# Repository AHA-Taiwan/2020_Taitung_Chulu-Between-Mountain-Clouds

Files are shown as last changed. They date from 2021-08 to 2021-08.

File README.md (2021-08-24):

# 2020｜台東初鹿｜山嵐。之間
## _Chulu Between the Mountain Clouds_, Taitung, Taiwan

>Humanitarian Architecture in Taitung<br/>
>
>以台灣國產木材為主體構築材料之人道建築案例，主要材料來源自：行政院農業委員會林務局「台灣木材」標章、正昌製材有限公司「台灣杉」及東皇昌五金工具有限公司。由 L.A. Lab 俐場域建築設計發展設計，與公東高工家具木工科/室內設計科/建築科、南港高工土木科、淡江大學建築研究所和雲林科技大學室內設計與建築系等學校單位合作進行實作。以山行為意象，行為活動為風，使人行自然共構穿梭其中。篩入的樹影搖曳數算著時光，試圖以空間為時間的記錄器，路徑則為不同時序打造的環境圖像，提供初鹿中學多一個停留與遊歷場所的可能。<br/>

## 基地環境：<br/>
台灣東南地區，北回歸線以南，有焚風、颱風、東北季風，海風具高度鹽分，設計時需注意材料防潮防蝕保護。<br/>
* 基地環境氣象資料：https://www.cwb.gov.tw/V8/C/W/County/County.html?CID=10014 <br/>
* 氣象觀測歷史紀錄：<br/>
  https://e-service.cwb.gov.tw/HistoryDataQuery/DayDataController.do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 <br/>
  
* 台東縣氣候月平均氣溫、月平均降雨量、風速與相對濕度數據圖表<br/>
 （取自交通部中央氣象局，統計期間為 1991-2020年）<br/>



* Google Map 位置：https://goo.gl/maps/nYVf215Q8UMeJW5S6  <br/>


***
## 專案介紹：<br/>

* 主要建材：台灣杉 [ 3.8 x 8.9 x 360 cm ] 尺寸。
  <br/>
* 數位模型［ 整體木構 3D ］：https://skfb.ly/op8NG

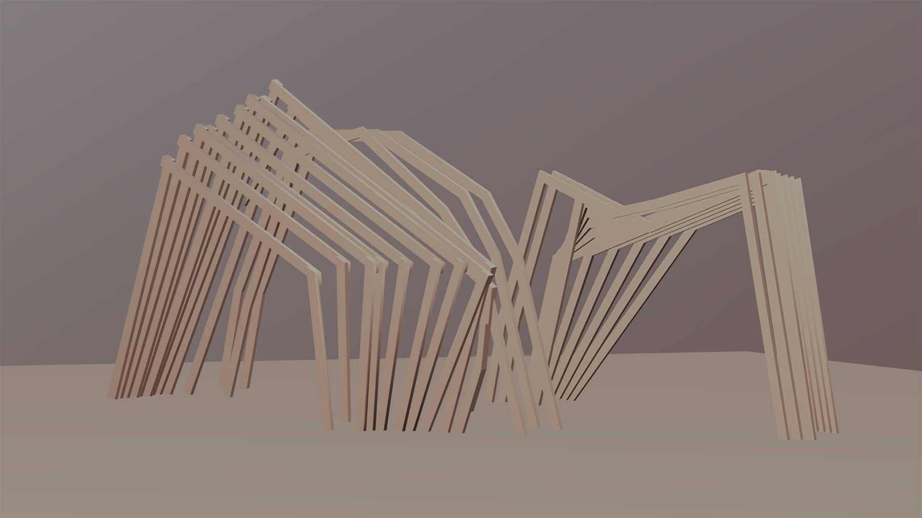
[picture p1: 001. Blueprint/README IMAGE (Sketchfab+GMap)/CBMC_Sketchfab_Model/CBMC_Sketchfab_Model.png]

<br/>
<br/>
***
## 如何達成合作建造：<br/>
* 請參閱［初次合作建造就上手 Collab-Const-Quick-Guide］：<br/>
https://github.com/AHA-Taiwan/Collab-Const-Quick-Guide/wiki <br/>
***
## 確保工作安全：<br/>
* 請參閱［合作建造-安全規範 Collab-Const-Safety］：<br/>
https://github.com/AHA-Taiwan/Collab-Const-Safety/wiki <br/>
***
## 探索合作資源：<br/>
* 請參閱［合作建造-資源探索 Collab-Const-Source］：<br/>
https://github.com/AHA-Taiwan/Collab-Const-Source/wiki <br/>
***
## 取得建造知識：<br/>
* 關於一般的常用構造技術（Techniques），請參閱［合作建造-學習知識 Collab-Const-Learning］：<br/>
https://github.com/AHA-Taiwan/Collab-Const-Learning/wiki <br/>
* 關於本案的特殊構築技術（Tectonic）， 請參閱［本案資料夾 002. Handbook］：<br/>
https://github.com/AHA-Taiwan/2020_Taitung_Chulu-Between-the-Mountain-Clouds/tree/main/002.%20Handbook<br/>
***

> #### 歡迎參與專案開發，Branch合併可向專案管理者提出請求

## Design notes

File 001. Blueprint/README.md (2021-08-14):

2D CAD (.dwg)<br/>
2D PDF<br/>
3D Models (.skp)<br/>
README IMAGE (Sketchfab+GMap)<br/>

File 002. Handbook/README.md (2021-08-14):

Assembly-Object Coding--物件組裝編碼<br/>
Constr-Process Handbook (pdf+ppt)--施工手冊與簡報<br/>
Constr-Process Sheet (.doc)--工項工序表<br/>

Constr-Method --施工工法, Link: https://drive.google.com/drive/u/4/folders/1Tx6Cp3CPNwddxzzepcwecKHZT5yJOXi1

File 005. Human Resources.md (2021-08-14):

# 專業者佈局與人力成本紀錄 
主要紀錄整體施工過程中，專業者、準專業者、非專業者於不同工項所花費時數，從中可間接推估建造施工人力經費及時間成本。
專業者M、準專業者P、非專業者N，當地人加註C

***
## 一、基礎施工
|人力編碼|當地人|工作總時數(hrs)|請工|換工|志工|
|:-:|:-:|:-:|:-:|:-:|:-:|
|M01 | |8 | | |V |
|M02 | |8 | | |V |
|M03 | |8  | | |V |
|P01 | |8 | | |V |
|P02 | |8 | | |V |
|P04 | |8 | | |V |
|P05 | |8 | | |V |
|P06 | |8 | | |V |
|P07 | |8 | | |V |
|P08 | |8 | | |V |
|P09 | |8 | | |V |
|P010 | |8 | | |V |
|P011 | |8 | | |V |
|P012 | |8 | | |V |
***
## 二、桿件結構
|人力編碼|當地人|工作總時數(hrs)|請工|換工|志工|
|:-:|:-:|:-:|:-:|:-:|:-:|
|M01 | |48 | | |V |
|M02 | |48 | | |V |
|M03 | |48 | | |V |
|P01 | |48 | | |V |
|P02 | |48 | | |V |
|P04 | |48 | | |V |
|P05 | |48 | | |V |
|P06 | |48 | | |V |
|P07 | |48 | | |V |
|P08 | |48 | | |V |
|P09 | |48 | | |V |
|P010 | |48 | | |V |
|P011 | |48 | | |V |
|P012 | |48 | | |V |
***
## 三、表面處理（上護木漆）
|人力編碼|當地人|工作總時數(hrs)|請工|換工|志工|
|:-:|:-:|:-:|:-:|:-:|:-:|
|M01 | |16 | | |V |
|M02 | |16 | | |V |
|M03 | |16 | | |V |
|P01 | |16 | | |V |
|P02 | |16 | | |V |
|P04 | |16 | | |V |
|P05 | |16 | | |V |
|P06 | |16 | | |V |
|P07 | |16 | | |V |
|P08 | |16 | | |V |
|P09 | |16 | | |V |
|P010 | |16 | | |V |
|P011 | |16 | | |V |
|P012 | |16 | | |V |
***

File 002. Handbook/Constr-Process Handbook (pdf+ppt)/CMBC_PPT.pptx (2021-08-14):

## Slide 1

2020

初鹿義築．工作手冊

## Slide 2

目錄

一．活動簡述．．．．．．．．．．．．１
二．自備物品與重要叮嚀．．．．．．．２
三．每日作息與行事曆．．．．．．．．４
四．交通與地圖．．．．．．．．．．．６
五．附件．．．．．．．．．．．．．．７
各組分工負責人
值日生班表
通訊錄

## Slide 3

１

一．活動簡述

時間：2020年8月19日 —2020年8月28日
地點：台東縣卑南鄉初鹿國中（台東縣卑南鄉明峰村忠孝路2號）
住宿：初鹿國中圖書室

夏天是明亮的，太陽是辣的，
青春的心是熱血的。
離開了繁華，重返樸實；
捨棄了依賴，回歸自立。

參與團體

外界交流

聯新文教基金會
台東初鹿教會
台東捷陞租車

材料贊助

行政院農委會林務局
正昌製材（台灣杉）
東皇昌五金行

俐場域建築設計
納樊司工作室
公東高工
家具木工科／室內設計科／建築科
義築工具圖書館
老麥農場露營區
台東縣政府文化處
社團法人台東縣巴蘭文化發展協會
社團法人台灣義築協會

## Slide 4

２

二．自備物品與重要叮嚀

換洗衣物 | 輕便工作服／衣架／曬衣夾／塑膠袋／洗衣用具／肥皂
盥洗用品 | 潔牙用品／毛巾／沐浴用品／吹風機
個人衛生品 | 衛生紙／濕紙巾／生理用品
個人藥物 | 健保卡／防蚊液／防曬乳／藥膏／個人用藥
必備物品 | 手電筒／睡袋／麥克筆／抹布
餐具 | 環保餐具／水壺
其他 | 帽子／外套／雨具／筆記／糧食／相機／袖套 足夠的零用金＆快樂心

重要叮嚀

1. 校園蛇類出沒，夜間活動務必攜帶手電筒，並尊重當地生態環境 。
2. 為避免影響施工進度，請按作息表活動，請勿飲酒 。
3. 避免使用香味濃郁的盥洗用品，易引來蚊蟲 。
4. 請留意貴重物品 。
5. 請注意當地禁忌，活動請結伴同行 。
6. 當地提款與融資服務不便，請攜帶足夠的現金 。
7. 施工區域內請勿穿脫鞋或涼鞋，並時時補充水分。
8. 由於浴室數量有限，洗澡時間限制十分鐘。

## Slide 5

３

最重要的三件事！！
1. 晚間收工前30分鐘，清點材料、工具
2. 收工前15分鐘，整理工作環境
3. 工地危險，務必攜帶安全帽，著長褲及全包覆鞋，勿著涼拖鞋
-工具配件務必妥善放回它的位置，切勿亂放
-建材勿隨意放置，會影響材料品質與建築壽命
-廢料勿扔棄，做好資源管理，這是對建築過程的尊重
-離隊務必告知組員、組長，個人行為將影響全體
-注意言行、態度，對自己負責，也尊重合作夥伴
-我們是一個大團體，務必保持與其他單位的良好互動
-我們是一個共同體，請關心身邊的伙伴，發揮自己的價值

施工注意事項

做一個謙卑的實踐者，感恩這份學習的機會

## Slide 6

４

三．每日作息與行事曆

（時間可能依每日天候狀況有所調整）

時間 | 活動 | 備註
0630 | Good Morning | 宿舍長叫醒大家
0630–0700 | 盥洗準備
0700–0730 | 活力早餐 | 生活組提前準備
0730–1200 | 木構GO GO！ | 施工組開工
1200–1300 | 午餐充電 | 生活組準備
1300–1730 | 木構GO GO GO！ | 施工組開工
1730–1830 | 晚餐時光 | 生活組準備
1830–1900 | 工作會議 | 進度／工地狀況檢討
1900–2000 | 洗澎澎 | 超時斷水電！
2000–2200 | 小組／個人時間 | 工作日誌／影音整理
2200 | 睡飽睡好 | 十點準時熄燈

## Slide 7

５

行事曆

08/19 （三）

認識大家／基礎前置加工

08/21 （五）

08/20 （四）

基礎前置加工／放樣／灌漿

木料分類標號／尺寸標記

08/23 （日）

08/22 （六）

木料加工：斬斷／引孔／導角

木料加工：斬斷／引孔／導角

08/24 （一）

木構系統單元化組裝

08/25 （二）

08/26 （三）

木構系統單元化組裝

木構單元與基礎固定

08/27 （四）

08/28 （五）

表面處理／護木漆／環境清潔

表面處理／護木漆／環境清潔／撤收

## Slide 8

６

四．交通與地圖

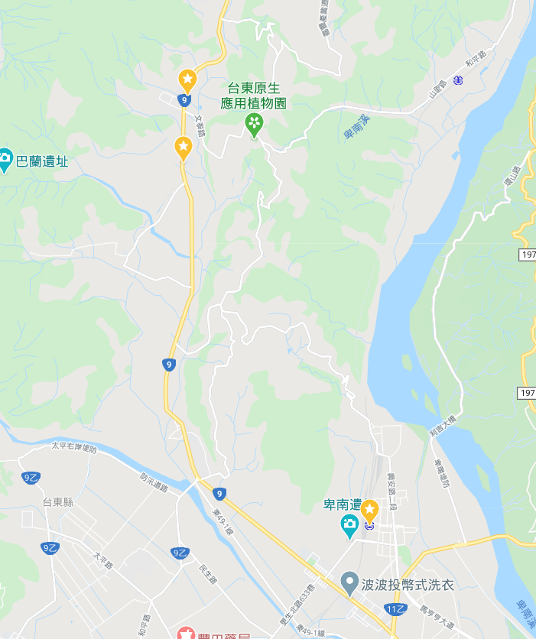
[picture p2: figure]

初鹿教會

盥洗

初鹿國中

加工／施工／住宿

台東車站

由　臺東車站　前往　初鹿國中

步行（15分鐘）至南王站牌
搭乘8171號公車（45分鐘）至初鹿國中

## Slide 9

８

值日生班表

日期 | 生活值日生 | 住宿值日生
8/19 | 瑋聖 仁楷 | 正威 昊翰
8/20 | 偵慧 文慧 | 玥綾 柏翔
8/21 | 仁楷 正威 | 昊翰 震洋
8/22 | 文慧 玥綾 | 柏翔 甫亘
8/23 | 正威 昊翰 | 震洋 瑋聖
8/24 | 玥綾 柏翔 | 甫亘 偵慧
8/25 | 昊翰 震洋 | 瑋聖 仁楷
8/26 | 柏翔 甫亘 | 偵慧 文慧
8/27 | 震洋 瑋聖 | 仁楷 正威
8/28 | 甫亘 偵慧 | 文慧 玥綾

住宿值日生工作
1. 寢室環境清潔
2. 廁所清潔及垃圾清理
3. 浴廁清潔

生活值日生工作
1. 工作環境整理
2. 餐後、廚餘整理
3. 清洗、收拾餐具
4. 搬運、發放食物

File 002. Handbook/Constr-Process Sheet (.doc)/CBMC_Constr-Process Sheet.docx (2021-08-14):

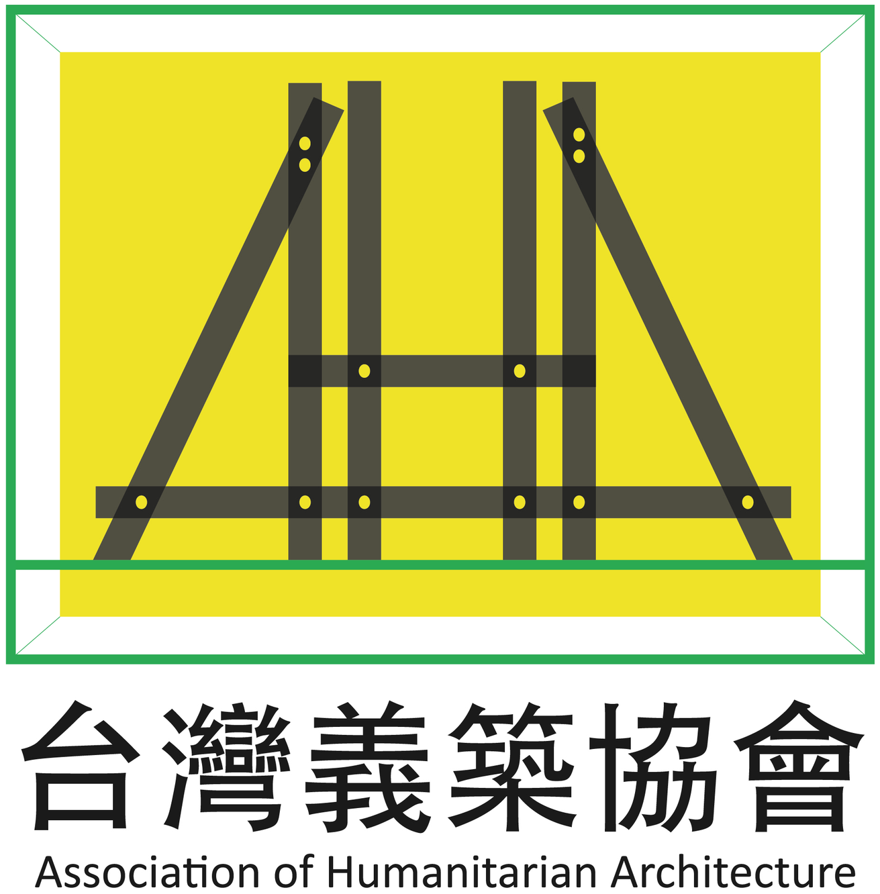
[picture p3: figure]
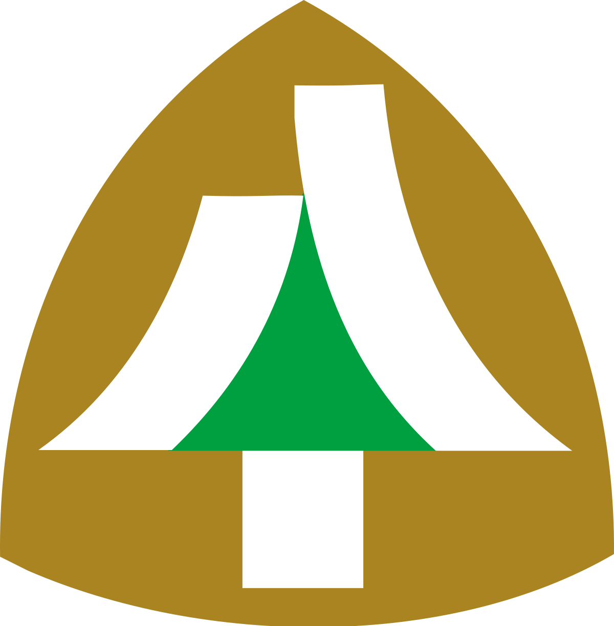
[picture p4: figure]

2020年 台東初鹿國中 入口意象 義築作品

生產製程文件

作業名稱 | 一、挑選木材 | 項次 | 作業順序 | | 備註

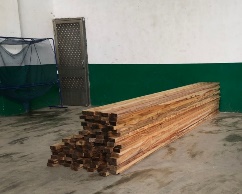
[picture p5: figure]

項次1-2 | | 1 | 目視木材彎曲程度
| | 2 | 依照彎曲程度分類用途
| | 項次 | 原料 | 設備 | 站別
| | a | 斷面3.8*8.9cm木料 | 無 | 木料區
| | b | 斷面3.8*8.9cm木料 | 無 | 木料區

作業名稱 | 二、木料處理 | 項次 | 作業順序 | | 備註

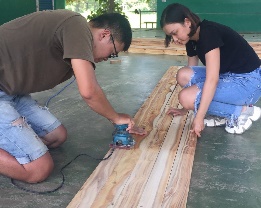
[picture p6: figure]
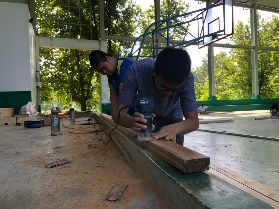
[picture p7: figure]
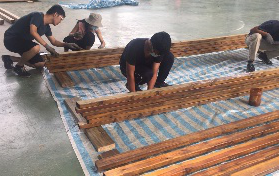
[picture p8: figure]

項次1 項次2 項次3 | | 1 | 導圓角
| | 2 | 砂磨
| | 3 | 上漆
| | 項次 | 原料 | 設備 | 站別
| | a | 斷面3.8*8.9cm木料 | 修邊機 | 加工區
| | b | 斷面3.8*8.9cm木料 | 砂磨機 | 加工區
| | c | 斷面3.8*8.9cm木料 底漆、面漆 | 油漆刷 | 加工區
作業名稱 | 三、木料加工 | 項次 | 作業順序 | | 備註

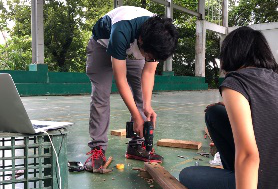
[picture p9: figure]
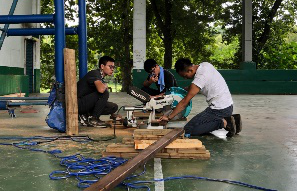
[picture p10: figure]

項次1 項次2 | | 1 | 木材裁切
| | 2 | 木材鑽孔
| | 項次 | 原料 | 設備 | 站別
| | a | 斷面3.8*8.9cm木料 | 斬斷機 | 裁切區
| | b | 斷面3.8*8.9cm木料 | 手持電鑽 | 加工區

作業名稱 | 四、木料單元組裝 | 項次 | 作業順序 | | 備註

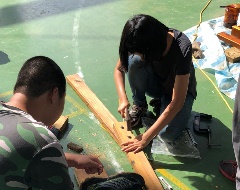
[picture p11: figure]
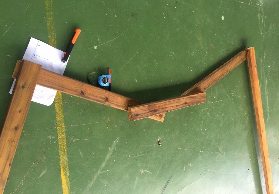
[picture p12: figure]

項次1 項次2 | | 1 | 將加工完的木料上下交疊 | | 加工區
| | 2 | 穿過牙條鎖上螺帽 | | 加工區
| | 項次 | 原料 | 設備 | 站別
| | a | 木材單元 | | 組裝區
| | b | 螺桿、螺帽 | 電動起子機、扳手 | 組裝區

（下頁）

作業名稱 | 五、安裝平台 | 項次 | 作業順序 | | 備註

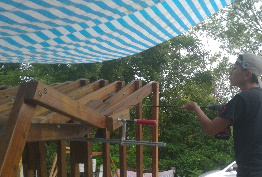
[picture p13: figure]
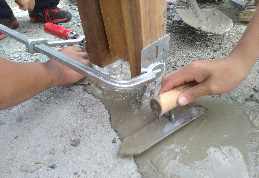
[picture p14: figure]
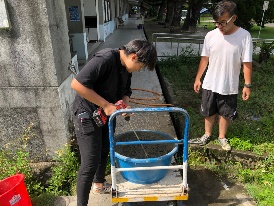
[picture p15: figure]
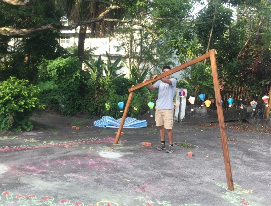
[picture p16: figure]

項次1 項次3 項次4 項次5 | | 1 | 放樣
| | 2 | 開挖
| | 3 | 拌水泥
| | 4 | 灌水泥固定鐵件
| | 5 | 各單元連接
| | 項次 | 原料 | 設備 | 站別
| | a | 無 | 水平儀、捲尺 | 基地
| | b | 無 | 水泥破碎機 | 基地
| | c | 水泥砂 | 圓鍬 方鏟 | 基地
| | d | 鐵件、單元構件 | 水平尺 | 基地
| | e | 單元構件、牙條、螺帽 | 電動起子機 | 基地

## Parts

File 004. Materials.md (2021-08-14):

# 材料清單與部件編碼紀錄 
主要紀錄整體施工過程中，各部位構件之材料名稱、規格、數量、單價、材料來源、廠商資訊等，從中可推估材料經費及運輸成本。

## 主要建材
|編碼|材料名稱|部件位置|規格|需要數量|實購數量|材料來源|
|:-:|:-:|:-:|:-:|:-:|:-:|:-:|
|S001|台灣杉|主體結構|3.8 x 8.9 x 360 cm|100|100|[正昌製材](http://www.wood.jen.com.tw/fengxi/front/bin/home.phtml)|
***
## 五金材料
|編碼|材料名稱|部件位置|規格|數量|
|:-:|:-:|:-:|:-:|:-:|
|B001|不鏽鋼牙條||304不鏽鋼M10長度1M 3/8"|100支|
|B002|白鐵袋帽||3/8"|150個|
|B003|白鐵華司||3/8"，(厚1mm)|300個|
|B004|白鐵螺母||3/8"|300個|
***

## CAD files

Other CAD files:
001. Blueprint/2D CAD (.dwg)/CBMC_Front Elevation_Truss Components.dwg
001. Blueprint/3D Models (.skp)/CBMC_Model_Original_All.skp
001. Blueprint/3D Models (.skp)/CBMC_Site Model.3dm
001. Blueprint/3D Models (.skp)/CBM_Model_Modified.skp

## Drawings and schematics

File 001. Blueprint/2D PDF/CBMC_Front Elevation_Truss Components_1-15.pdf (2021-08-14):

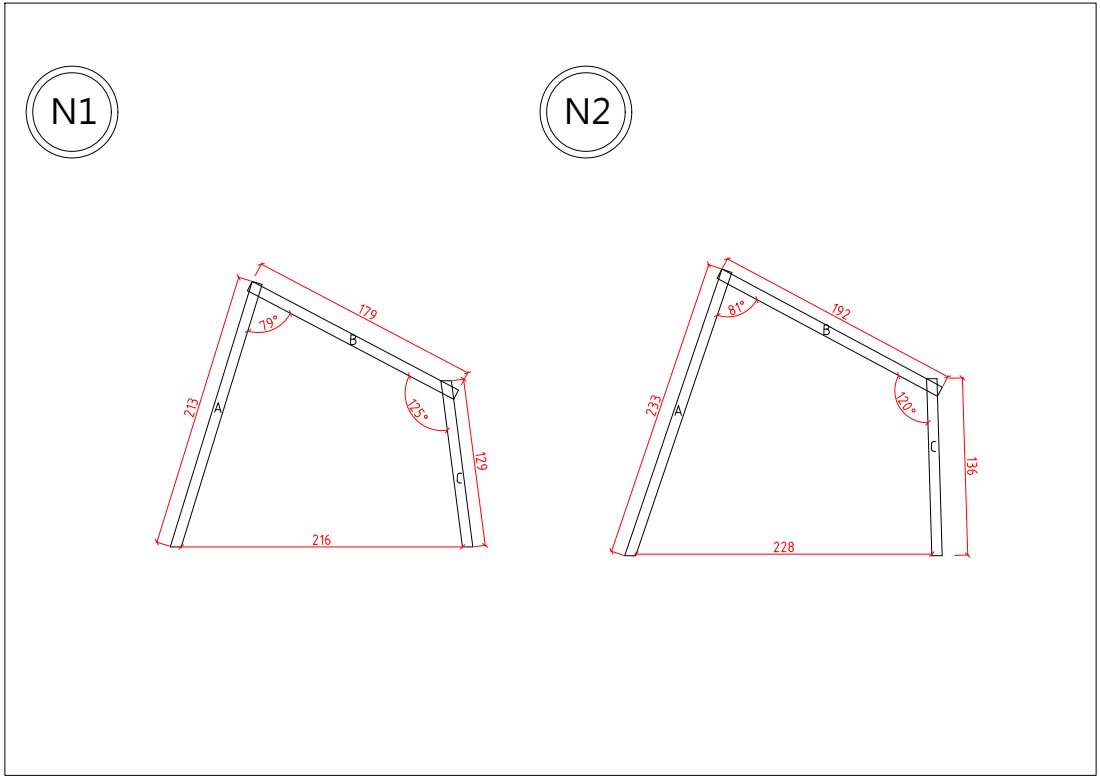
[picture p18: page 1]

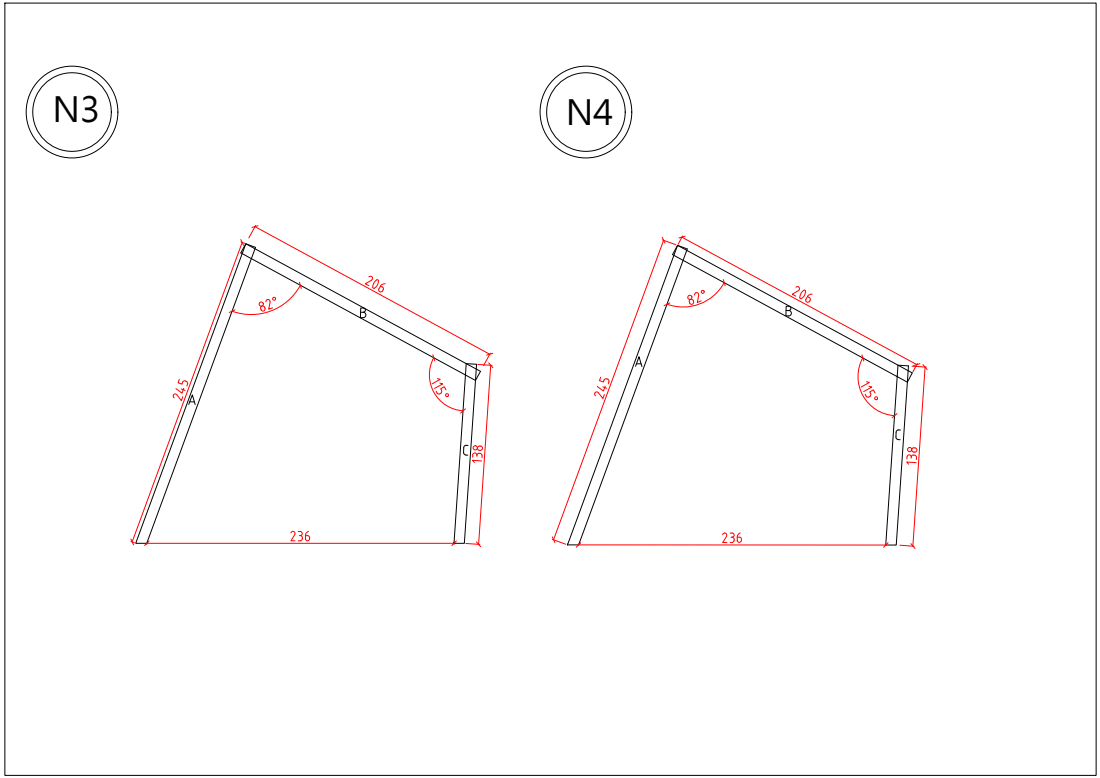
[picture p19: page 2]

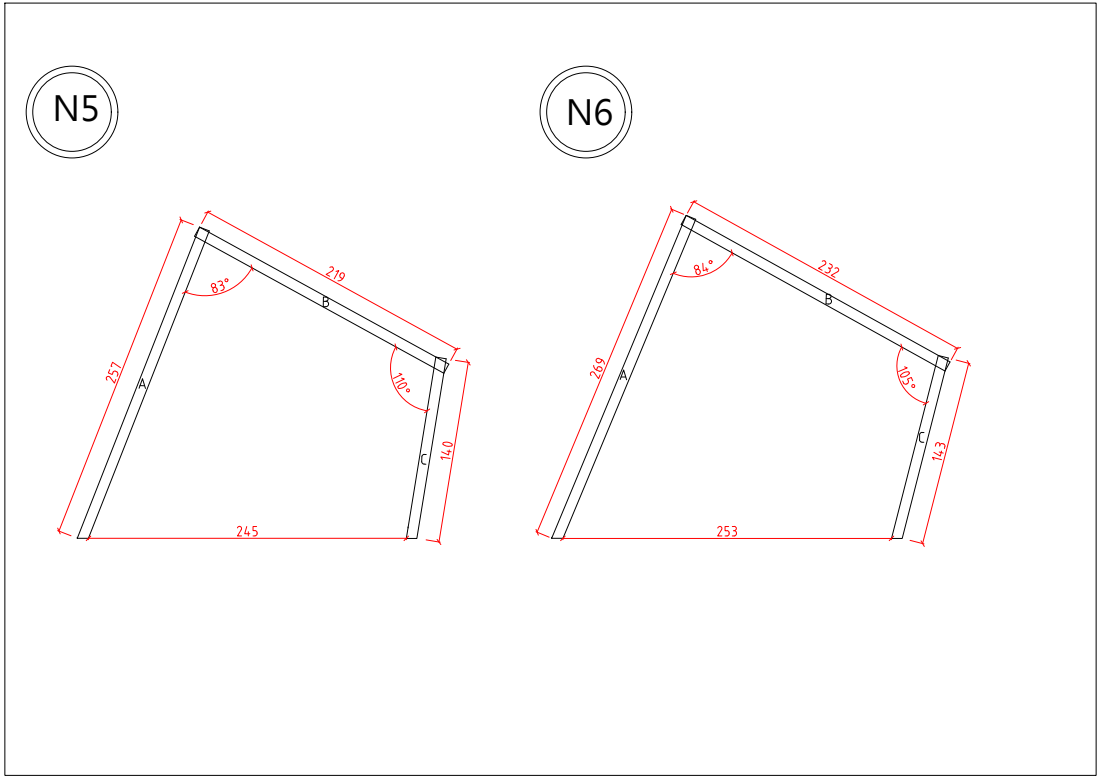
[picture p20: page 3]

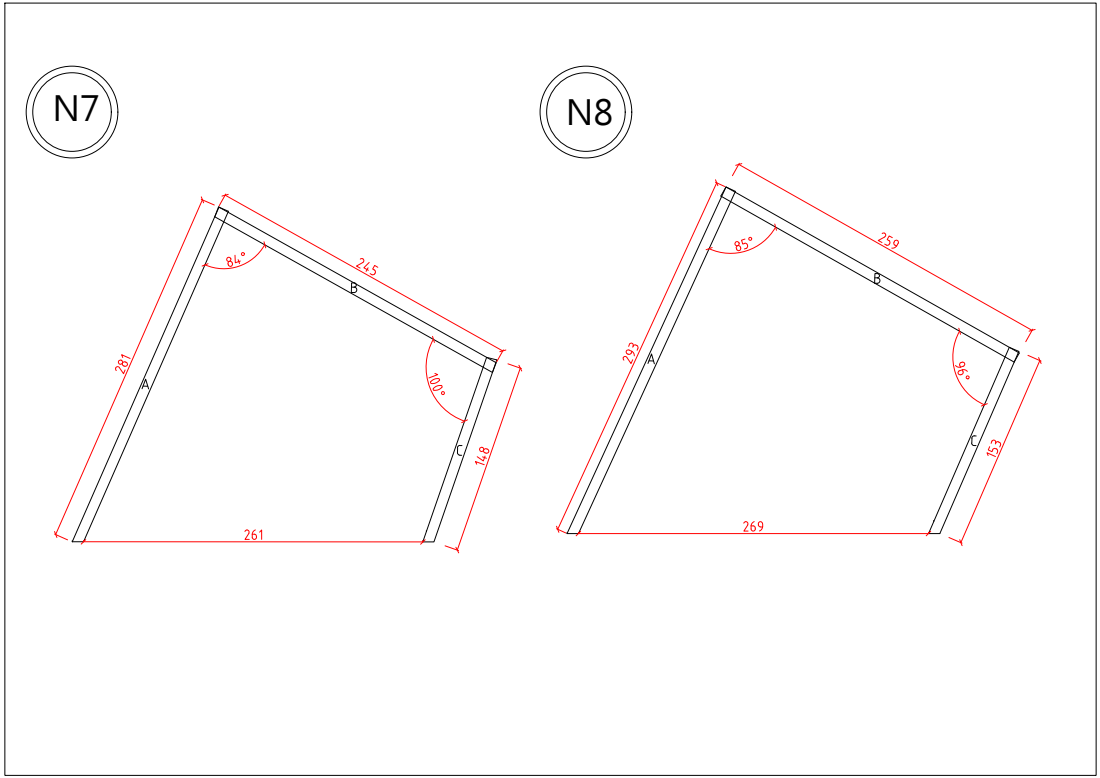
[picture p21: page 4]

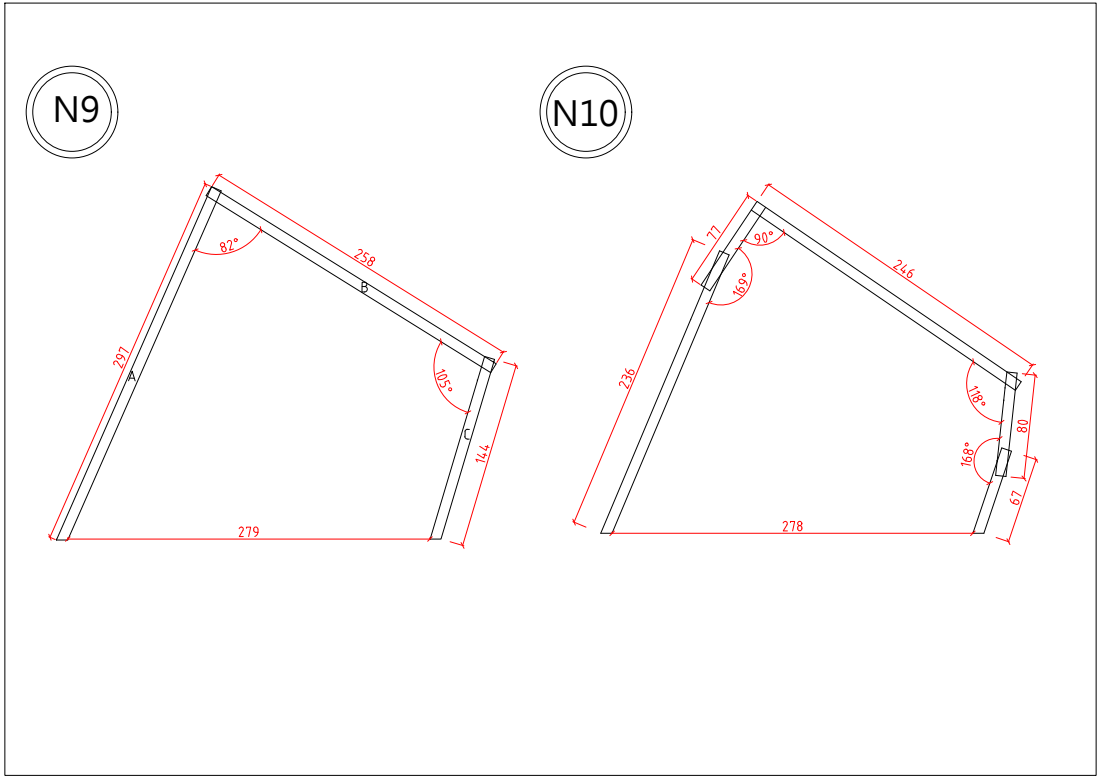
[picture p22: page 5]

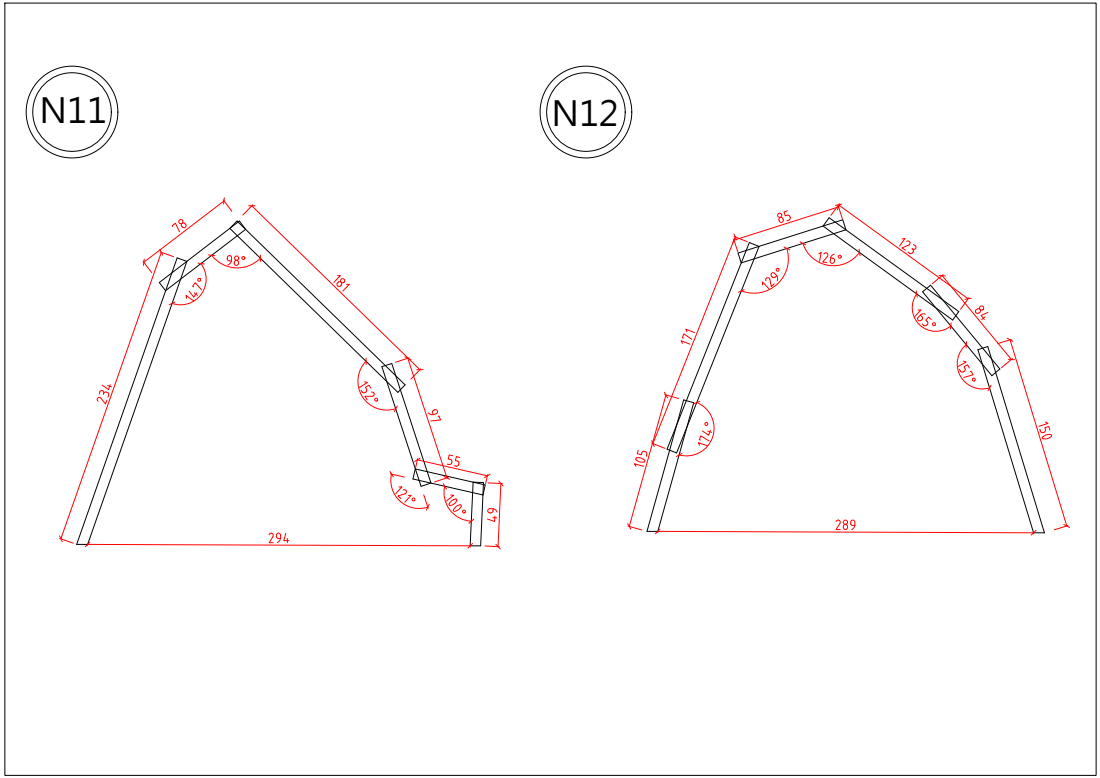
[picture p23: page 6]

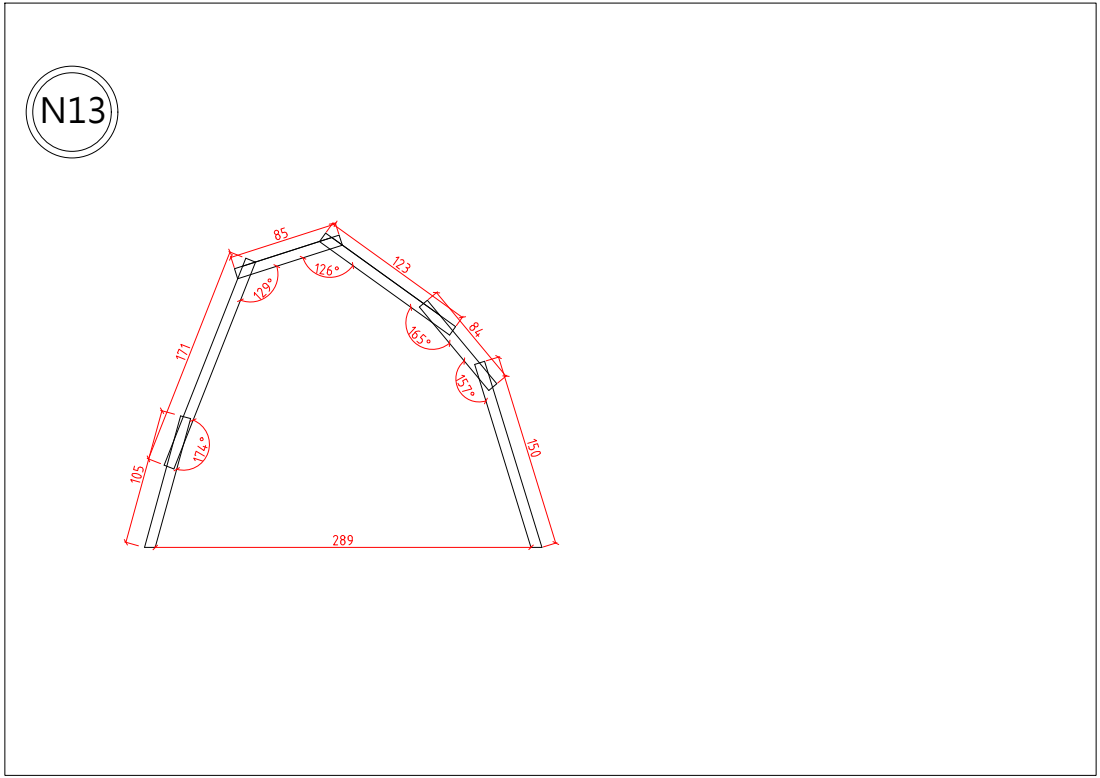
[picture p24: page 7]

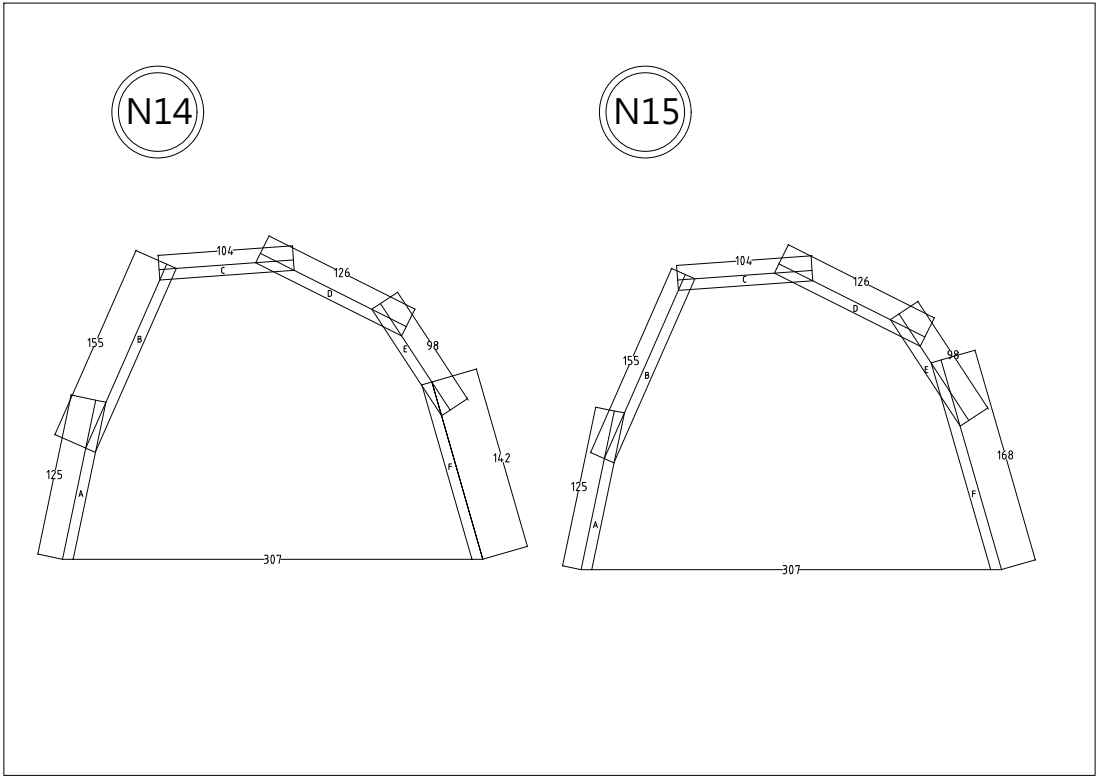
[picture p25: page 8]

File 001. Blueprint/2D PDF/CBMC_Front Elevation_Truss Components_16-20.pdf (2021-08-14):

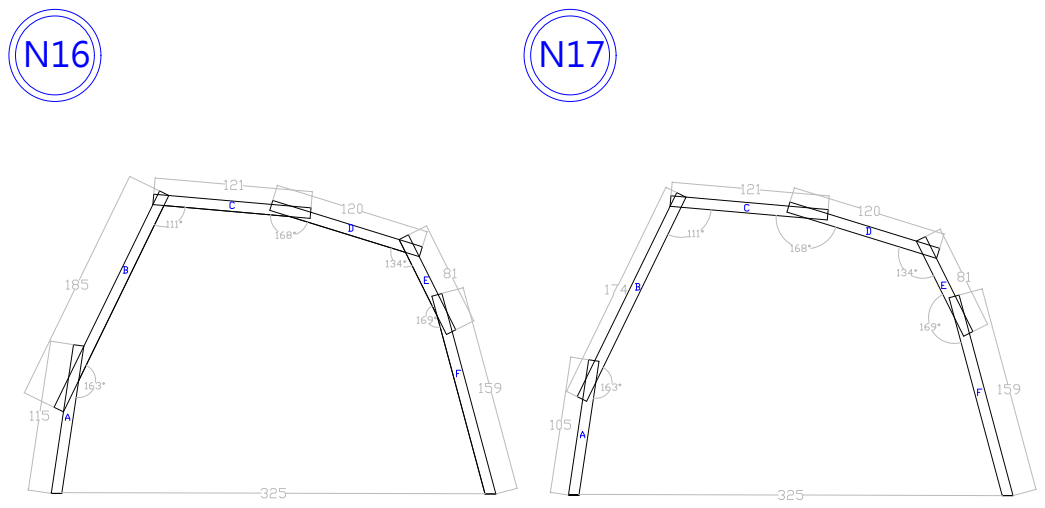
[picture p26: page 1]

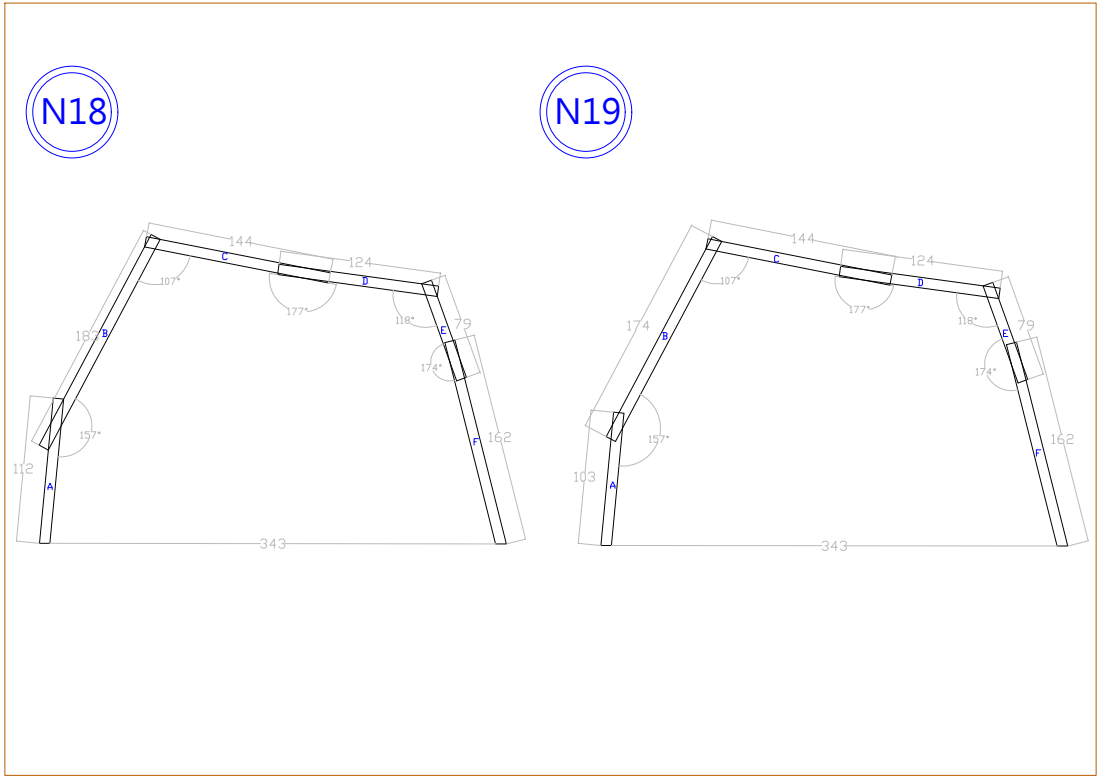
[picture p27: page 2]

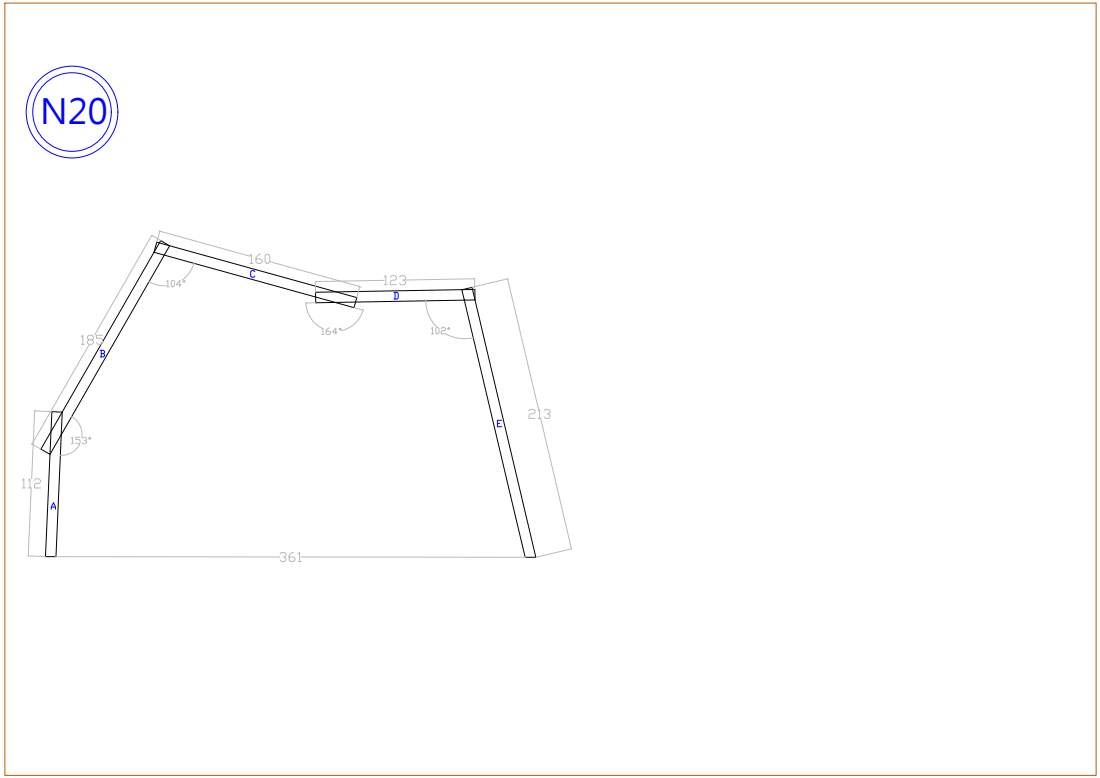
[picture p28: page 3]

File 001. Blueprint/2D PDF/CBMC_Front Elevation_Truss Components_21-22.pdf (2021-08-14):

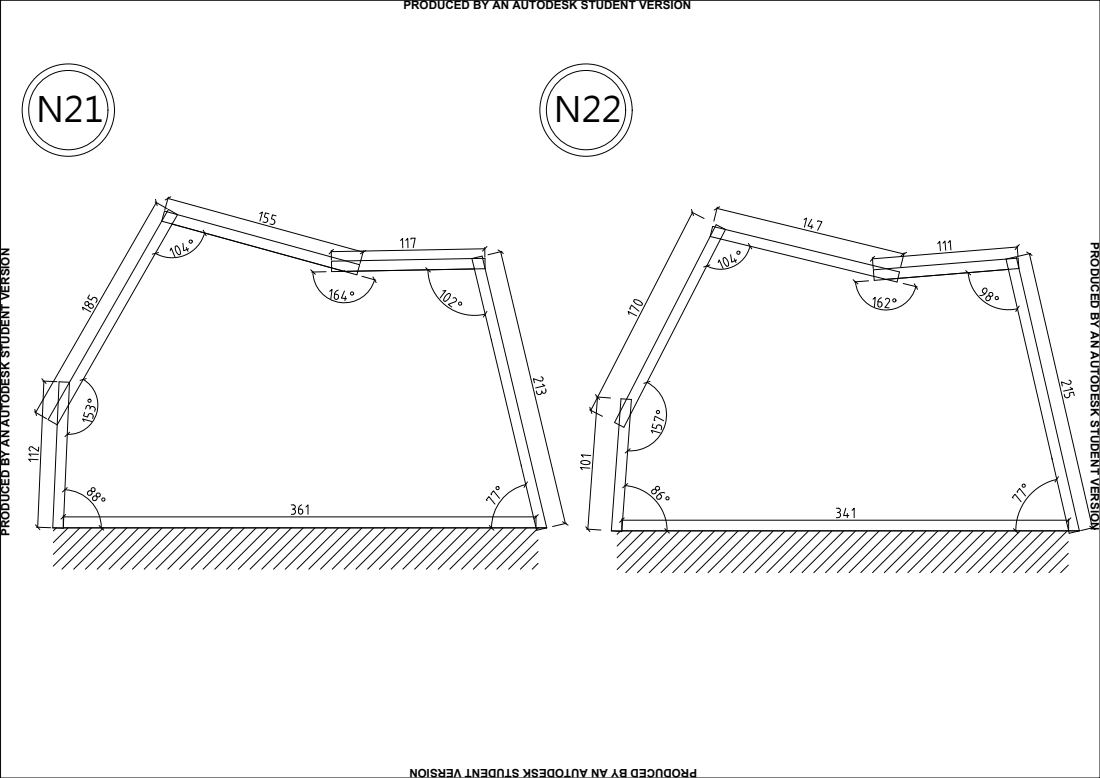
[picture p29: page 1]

PRODUCED BY AN AUTODESK STUDENT VERSION

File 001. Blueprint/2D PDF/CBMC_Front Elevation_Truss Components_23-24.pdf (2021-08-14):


PRODUCED BY AN AUTODESK STUDENT VERSION

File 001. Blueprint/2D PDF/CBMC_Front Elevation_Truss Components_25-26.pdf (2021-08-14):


PRODUCED BY AN AUTODESK STUDENT VERSION

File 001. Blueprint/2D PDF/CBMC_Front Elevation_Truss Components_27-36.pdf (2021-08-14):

N27 | N28


N29 | N30


N31 | N32


N33 | N34


PRODUCED BY AN AUTODESK STUDENT VERSION

N35 | N36


PRODUCED BY AN AUTODESK STUDENT VERSION
